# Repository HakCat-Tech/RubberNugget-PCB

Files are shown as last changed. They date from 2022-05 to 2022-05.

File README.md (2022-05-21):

# RubberNugget PCB v1.0 (alpha)
PCB design files for the RubberNugget.  More documentation coming soon!

## Features
- ESP32-S2 WiFi MicroController
- Native USB
- JTAG Debug
- Expansion Headers
- UART Breakout
- Qwiic Connector
- NeoPixel Breakout

## Fixes
- [ ] Antenna clearance
- [ ] Component layout
- [ ] Header pinout standard
- [ ] PCB Art

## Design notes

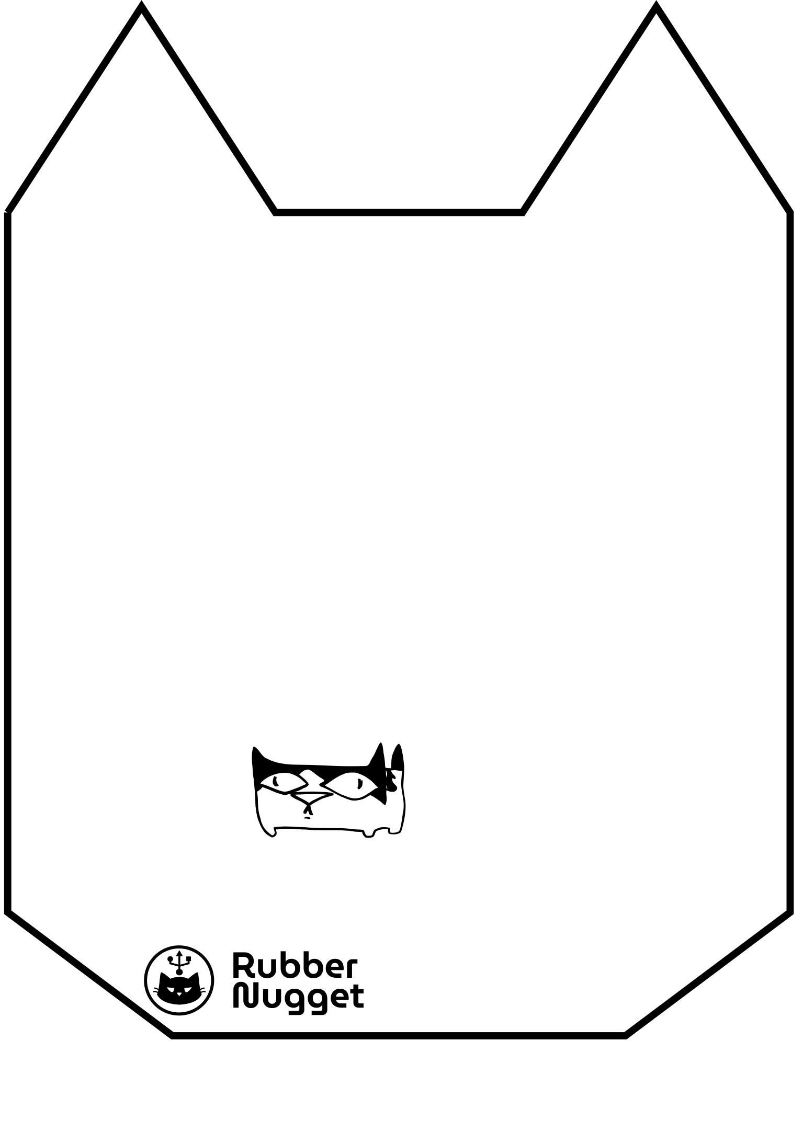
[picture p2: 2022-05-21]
RubberNugget/assets/.svg2shenzhen-cache/images/F.Cu_g824.png

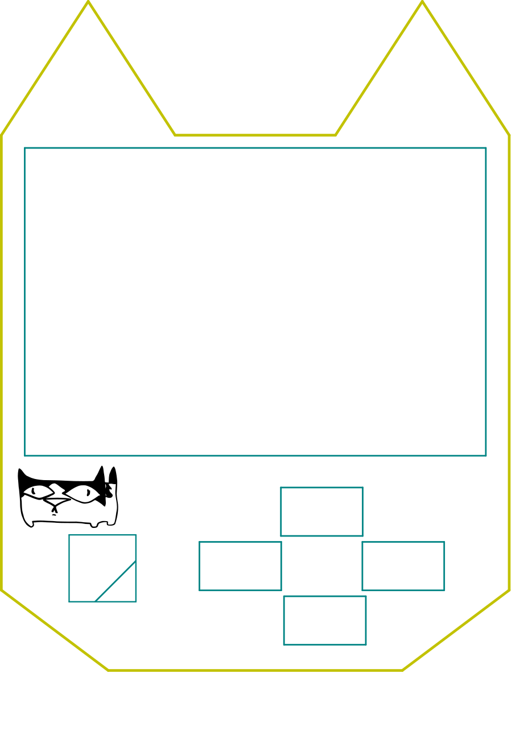
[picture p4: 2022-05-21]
RubberNugget/assets/.svg2shenzhen-cache/images/F.SilkS_g838.png

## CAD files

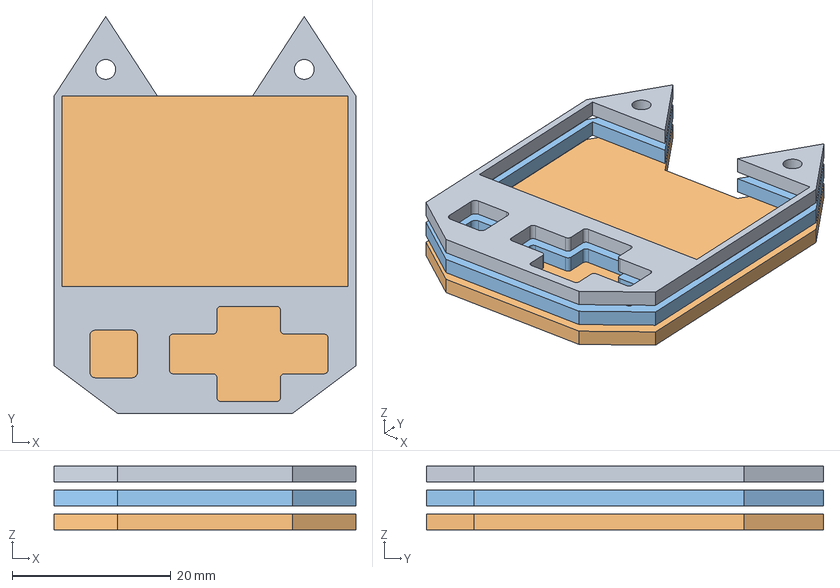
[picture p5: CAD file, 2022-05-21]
RubberNugget/Acrylic Case/RubberNugget-Outline.FCStd
38.0 x 50.0 x 8.00 mm
Faceplate
Backplate
Standoff

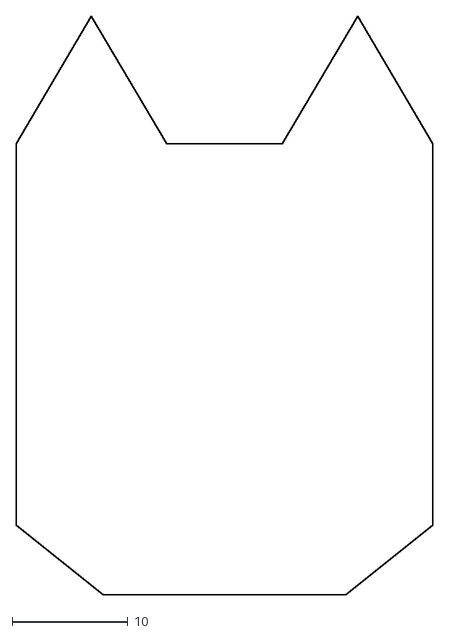
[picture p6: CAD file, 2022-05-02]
RubberNugget/assets/Board-Outline.dxf
36.0 x 50.0

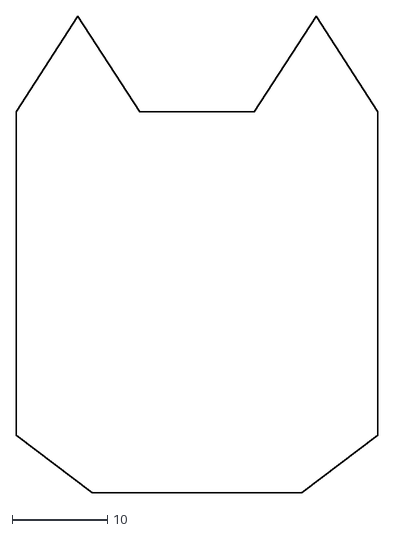
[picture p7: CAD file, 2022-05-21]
RubberNugget/assets/outline/RubberNugget.dxf
38.0 x 50.0

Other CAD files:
RubberNugget/assets/outline/RubberNugget-Outline.FCStd

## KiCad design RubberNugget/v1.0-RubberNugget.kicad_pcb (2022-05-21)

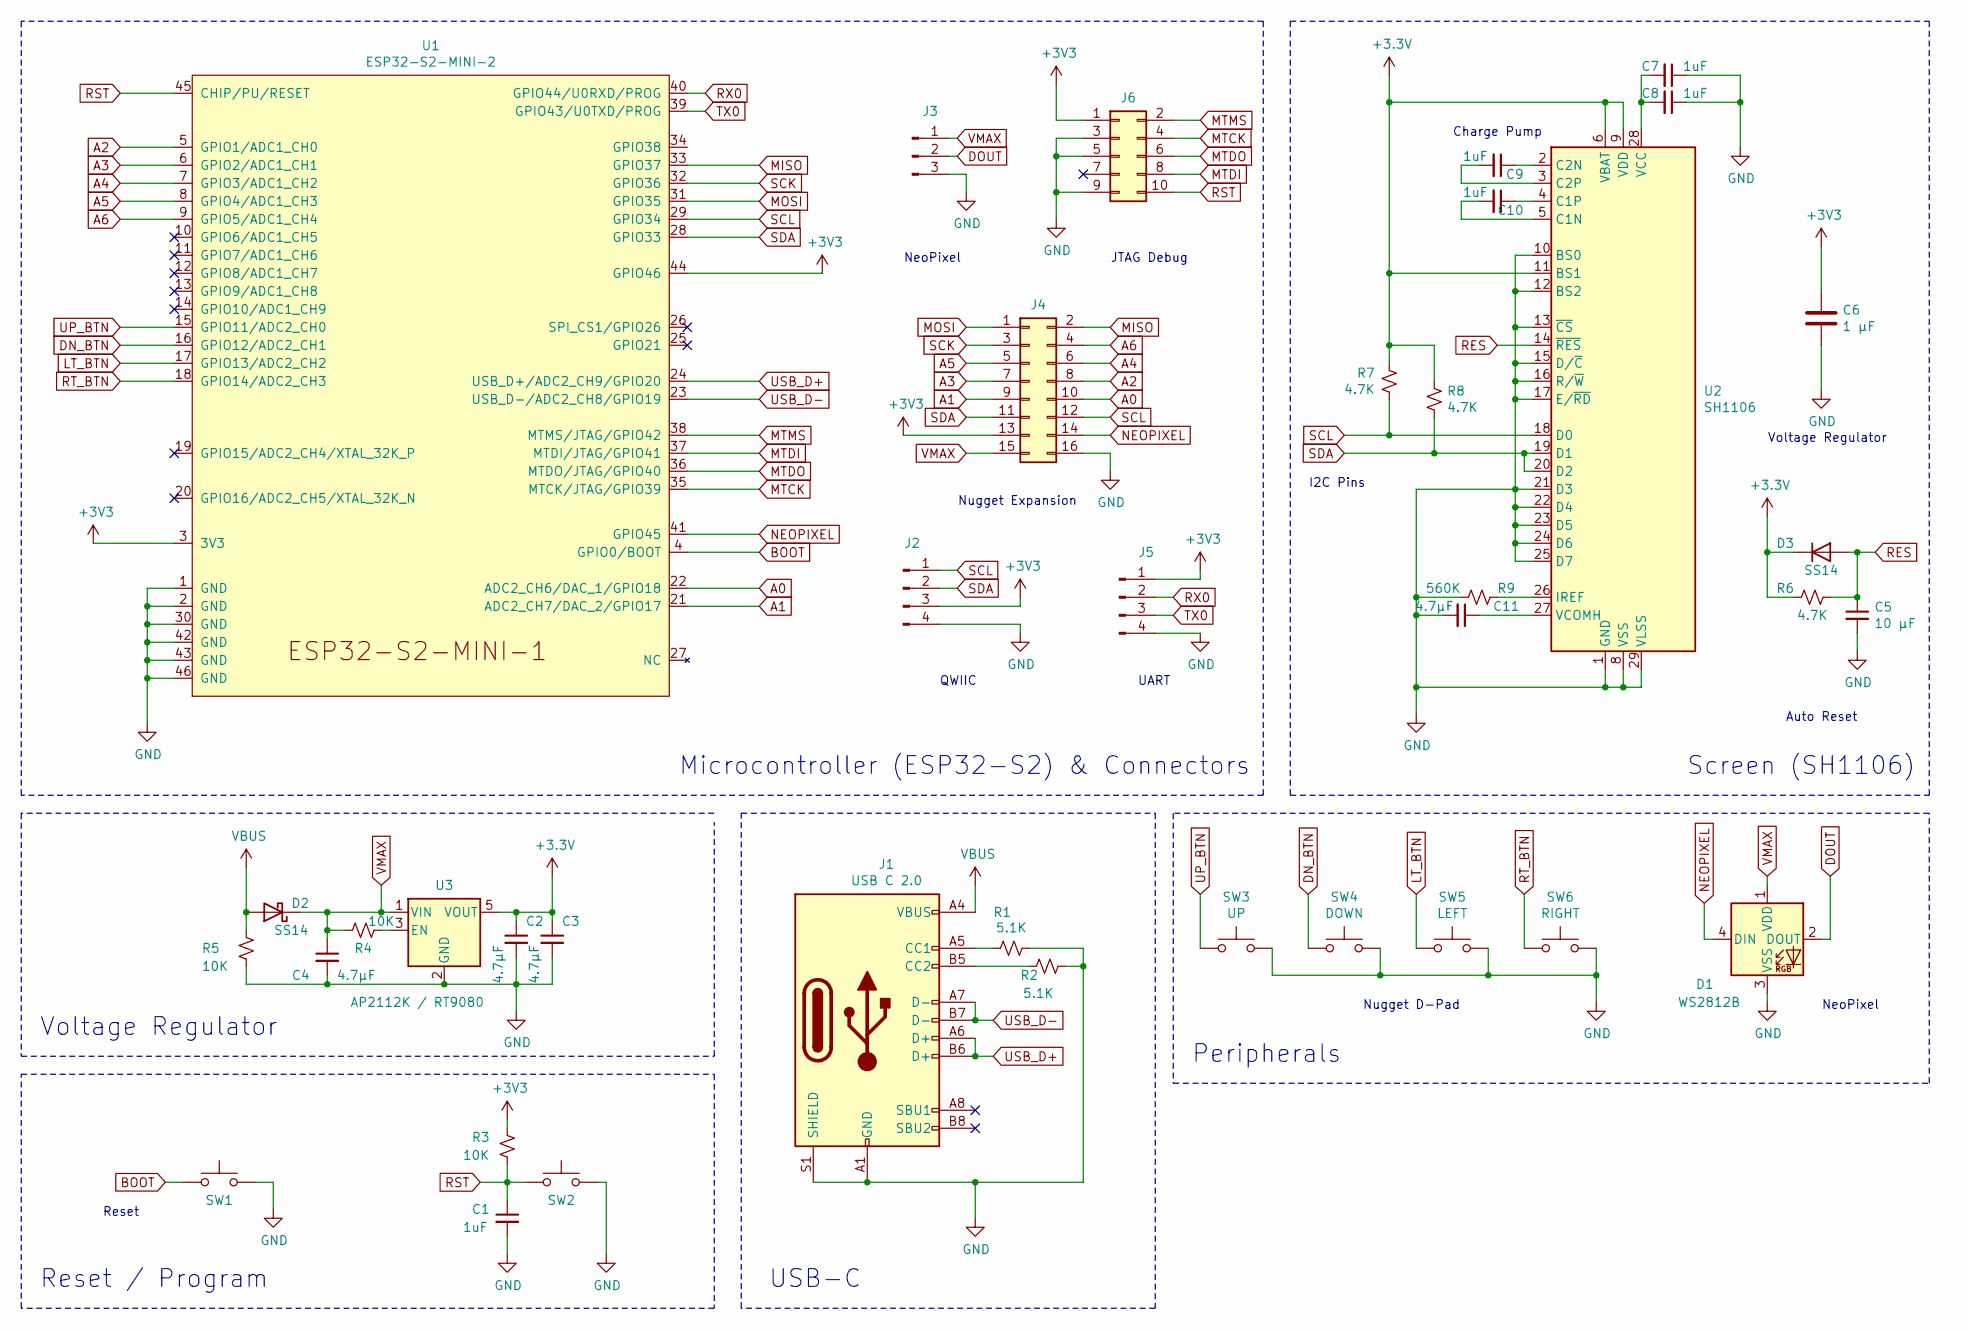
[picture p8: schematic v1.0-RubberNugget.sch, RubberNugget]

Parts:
C1, C7, C8, C9, C10: 1uF; C_0603_1608Metric_Pad1.08x0.95mm_HandSolder
C2, C3, C4, C11: 4.7μF; C_0603_1608Metric_Pad1.08x0.95mm_HandSolder
C5: 10 μF; C_0603_1608Metric_Pad1.08x0.95mm_HandSolder
C6: 1 μF; C_0603_1608Metric_Pad1.08x0.95mm_HandSolder
D1: WS2812B; LED_WS2812B_PLCC4_5.0x5.0mm_P3.2mm
D2, D3: SS14; D_SOD-323_HandSoldering
J1: USB C 2.0; USB_C_Receptacle_Palconn_UTC16-G
J2: QWIIC; JST_SH_SM04B-SRSS-TB_1x04-1MP_P1.00mm_Horizontal
J3: NeoPixel Breakout; JST_SH_SM03B-SRSS-TB_1x03-1MP_P1.00mm_Horizontal
J4: Nugget Expansion; PinHeader_2x08_P1.27mm_Vertical_SMD
J5: UART; JST_SH_SM04B-SRSS-TB_1x04-1MP_P1.00mm_Horizontal
J6: JTAG; PinHeader_2x05_P1.27mm_Vertical_SMD
R1, R2: 5.1K; R_0603_1608Metric_Pad0.98x0.95mm_HandSolder
R3, R4, R5: 10K; R_0603_1608Metric_Pad0.98x0.95mm_HandSolder
R6, R7, R8: 4.7K; R_0603_1608Metric_Pad0.98x0.95mm_HandSolder
R9: 560K; R_0603_1608Metric_Pad0.98x0.95mm_HandSolder
SW1, SW2: Reset; Panasonic_EVQPUM_EVQPUD
SW3: UP; SW_SPST_FSMSM
SW4: DOWN; SW_SPST_FSMSM
SW5: LEFT; SW_SPST_FSMSM
SW6: RIGHT; SW_SPST_FSMSM
U1: ESP32-S2-MINI-2; ESP32-S2-MINI-1_Hand-Soldering
U2: SH1106; OLED-128O064D
U3: AP2112K / RT9080; SOT-23-5

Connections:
A0: J4.10, U1.22 (ADC2_CH6/DAC_1/GPIO18)
A1: J4.9, U1.21 (ADC2_CH7/DAC_2/GPIO17)
A2: J4.8, U1.5 (GPIO1/ADC1_CH0)
A3: J4.7, U1.6 (GPIO2/ADC1_CH1)
A4: J4.6, U1.7 (GPIO3/ADC1_CH2)
A5: J4.5, U1.8 (GPIO4/ADC1_CH3)
A6: J4.4, U1.9 (GPIO5/ADC1_CH4)
BOOT: SW1.1, U1.4 (GPIO0/BOOT)
DN_BTN: SW4.1, U1.16 (GPIO12/ADC2_CH1)
DOUT: D1.2 (DOUT), J3.2
GND: C1.2, C2.2, C3.2, C4.2, C5.2, C6.2, C7.1, C8.1, C11.2, D1.3 (VSS), J1.A1 (GND), J1.A12 (GND), J1.B1 (GND), J1.B12 (GND), J1.S1 (SHIELD), J2.4, J3.3, J4.16, J5.4, J6.3, J6.5, J6.9, R1.1, R2.2, R5.2, R9.2, SW1.2, SW2.2, SW3.2, SW4.2, SW5.2, SW6.2, U1.1 (GND), U1.2 (GND), U1.30 (GND), U1.42 (GND), U1.43 (GND), U1.46 (GND), U2.1 (GND), U2.8 (VSS), U2.10 (BS0), U2.12 (BS2), U2.13 (~CS), U2.15 (D/~C), U2.16 (R/~W), U2.17 (E/~RD), U2.21 (D3), U2.22 (D4), U2.23 (D5), U2.24 (D6), U2.25 (D7), U2.29 (VLSS), U2.30 (GND), U3.2 (GND)
LT_BTN: SW5.1, U1.17 (GPIO13/ADC2_CH2)
MISO: J4.2, U1.33 (GPIO37)
MOSI: J4.1, U1.31 (GPIO35)
MTCK: J6.4, U1.35 (MTCK/JTAG/GPIO39)
MTDI: J6.8, U1.37 (MTDI/JTAG/GPIO41)
MTDO: J6.6, U1.36 (MTDO/JTAG/GPIO40)
MTMS: J6.2, U1.38 (MTMS/JTAG/GPIO42)
NEOPIXEL: D1.4 (DIN), J4.14, U1.41 (GPIO45)
unnamed: C7.2, C8.2, U2.28 (VCC)
unnamed: C9.1, U2.2 (C2N)
unnamed: C9.2, U2.3 (C2P)
unnamed: C10.1, U2.4 (C1P)
unnamed: C10.2, U2.5 (C1N)
unnamed: C11.1, U2.27 (VCOMH)
unnamed: J1.A5 (CC1), R1.2
unnamed: J1.B5 (CC2), R2.1
unnamed: R4.1, U3.3 (EN)
unnamed: R9.1, U2.26 (IREF)
RES: C5.1, D3.2 (A), R6.1, U2.14 (~RES)
RST: C1.1, J6.10, R3.2, SW2.1, U1.45 (CHIP/PU/RESET)
RT_BTN: SW6.1, U1.18 (GPIO14/ADC2_CH3)
RX0: J5.2, U1.40 (GPIO44/U0RXD/PROG)
SCK: J4.3, U1.32 (GPIO36)
SCL: J2.1, J4.12, R7.2, U1.29 (GPIO34), U2.18 (D0)
SDA: J2.2, J4.11, R8.2, U1.28 (GPIO33), U2.19 (D1), U2.20 (D2)
TX0: J5.3, U1.39 (GPIO43/U0TXD/PROG)
UP_BTN: SW3.1, U1.15 (GPIO11/ADC2_CH0)
USB_D+: J1.A6 (D+), J1.B6 (D+), U1.24 (USB_D+/ADC2_CH9/GPIO20)
USB_D-: J1.A7 (D-), J1.B7 (D-), U1.23 (USB_D-/ADC2_CH8/GPIO19)
VBUS: D2.2 (A), J1.A4 (VBUS), J1.A9 (VBUS), J1.B4 (VBUS), J1.B9 (VBUS), R5.1
VMAX: C4.1, D1.1 (VDD), D2.1 (K), J3.1, J4.15, R4.2, U3.1 (VIN)

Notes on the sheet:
Microcontroller (ESP32-S2) & Connectors
Voltage Regulator
Auto Reset
I2C Pins
Charge Pump
NeoPixel
Nugget D-Pad
Screen (SH1106)
Peripherals
USB-C
Reset
Voltage Regulator
Reset / Program
QWIIC
NeoPixel
UART
JTAG Debug
Nugget Expansion

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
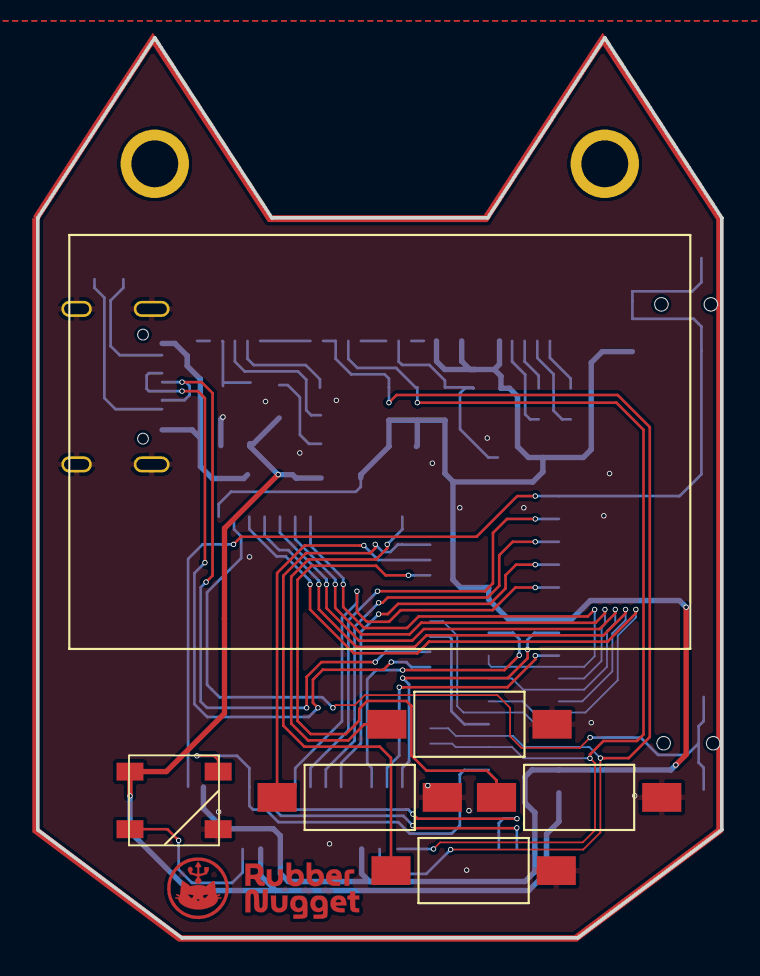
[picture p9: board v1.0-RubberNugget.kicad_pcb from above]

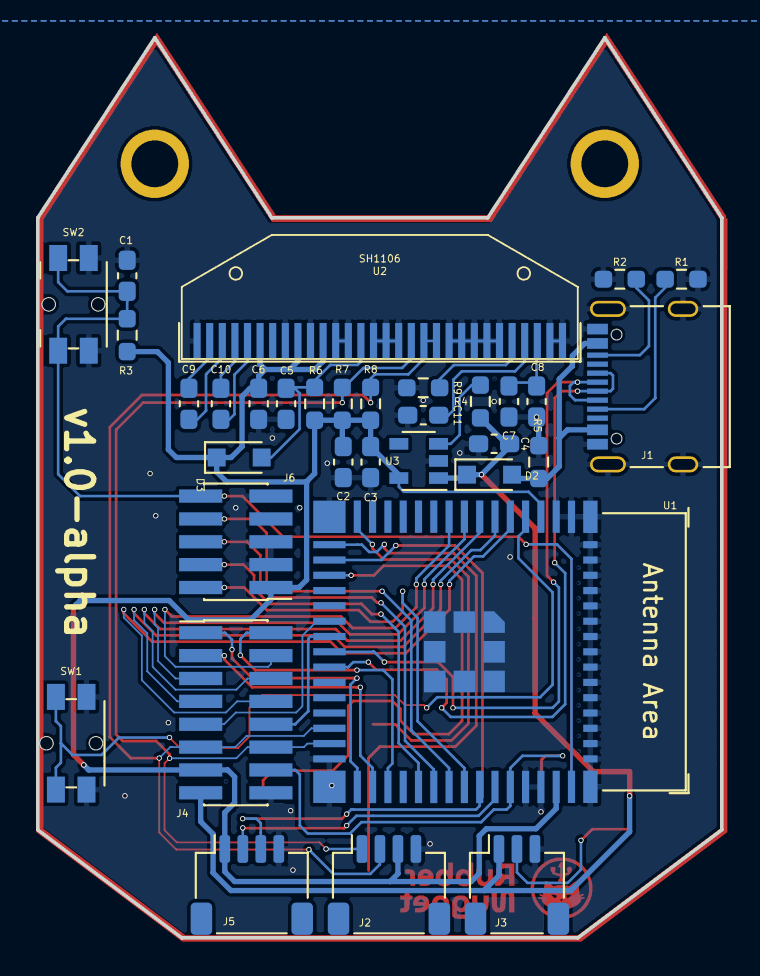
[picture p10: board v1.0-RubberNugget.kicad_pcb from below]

Board: 2 copper layers, 38.0 x 50.0 mm, 39 parts (33 on the bottom side), 43 nets.

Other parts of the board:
Ref**: Val**; art

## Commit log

2022-05-02 v1.0 RubberNugget schematic
2022-05-02 fix submodule
    [Board-Outline.FCStd, Board-Outline.dxf, v1.0-RubberNugget.kicad_pcb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]
2022-05-21 update and re-wire v1.0 alpha
    [Board-Outline.FCStd, RubberNugget-Outline.FCStd, RubberNugget.dxf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]
